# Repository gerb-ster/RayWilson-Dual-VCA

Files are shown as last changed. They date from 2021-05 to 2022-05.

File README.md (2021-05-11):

# Ray Wilson's Dual VCA

Somewhere I read that you can never have enough VCA’s, and I’ve build a number of them over the years. This one is a straight up clone of a design by the late Ray Wilson from Music From Outer Space. Really nice and versatile module.

## Status: Finished

- done: first schematic & board design
- done: breadboard and test
- done: design frontpanel
- done: order PCB and build prototype

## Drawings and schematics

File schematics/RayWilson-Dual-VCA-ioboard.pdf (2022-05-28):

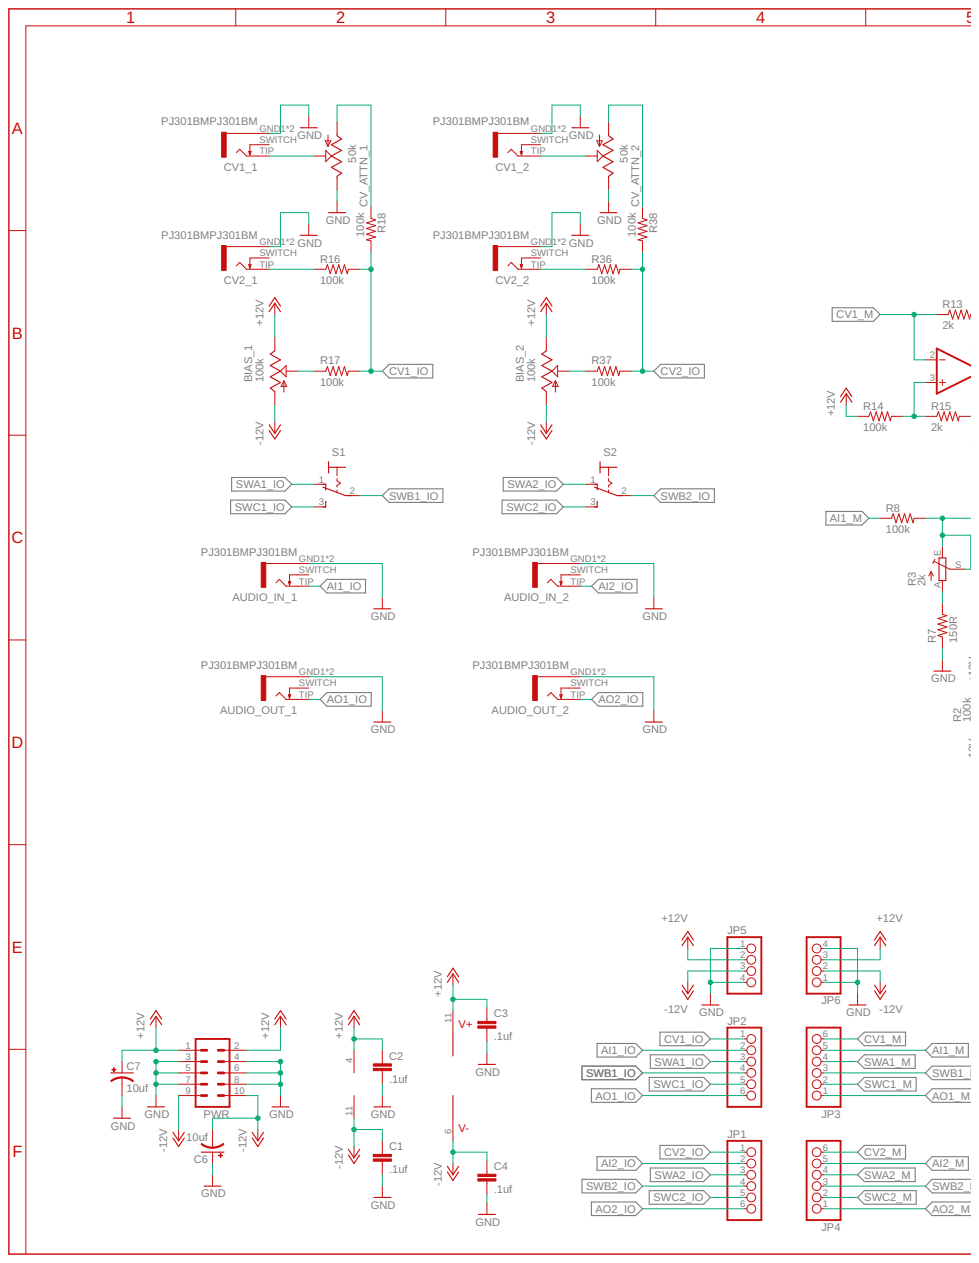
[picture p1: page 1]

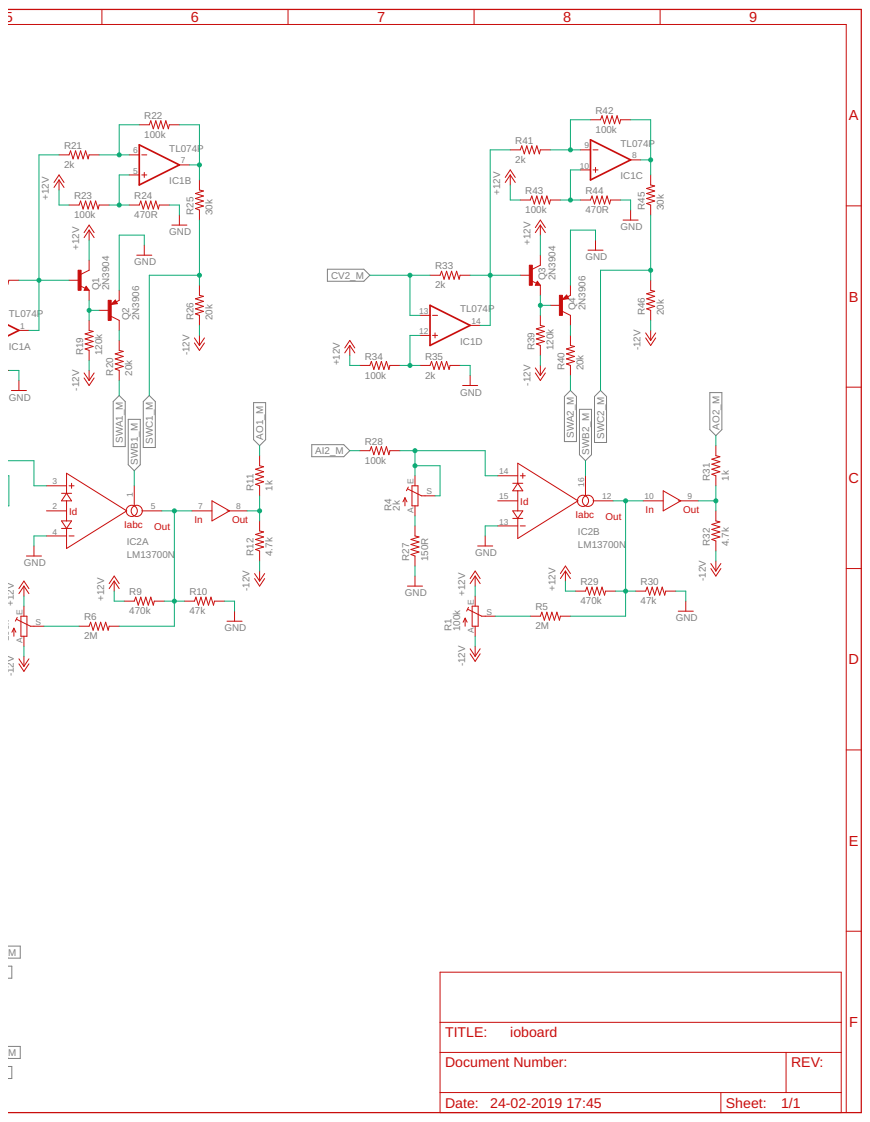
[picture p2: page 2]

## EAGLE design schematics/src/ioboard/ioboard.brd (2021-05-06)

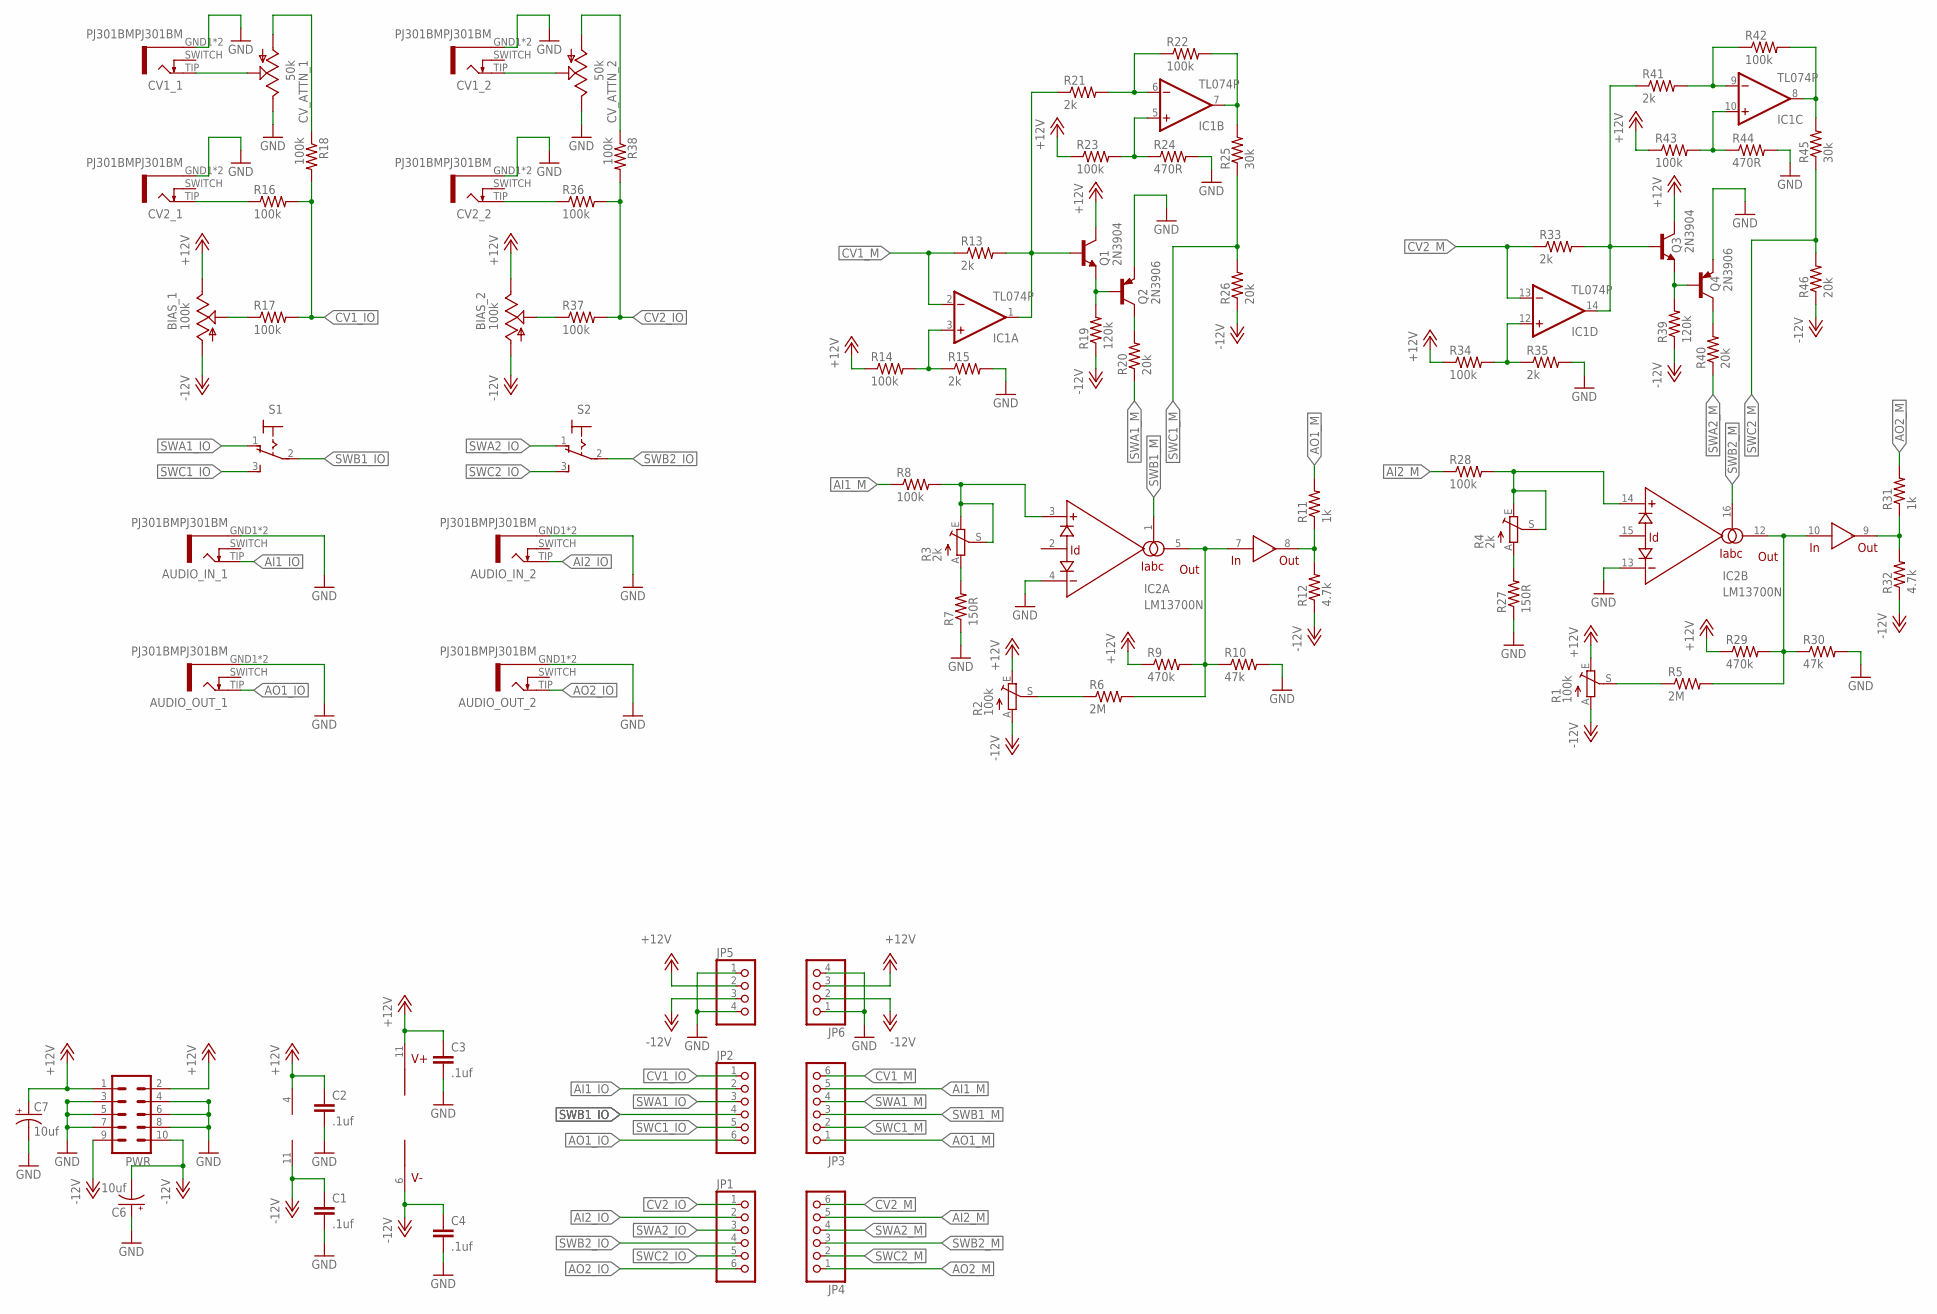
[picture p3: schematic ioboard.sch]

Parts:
AUDIO_IN_1, AUDIO_IN_2: PJ301BMPJ301BM; PJ301BM
AUDIO_OUT_1, AUDIO_OUT_2: PJ301BMPJ301BM; PJ301BM
BIAS_1, BIAS_2: 100k; EVUF
C1, C2, C3, C4: .1uf; C050-024X044
C6, C7: 10uf; E2,5-5
CV1_1, CV1_2, CV2_1, CV2_2: PJ301BMPJ301BM; PJ301BM
CV_ATTN_1, CV_ATTN_2: 50k; EVUF
IC1: TL074P; DIL14
IC2: LM13700N; DIL16
JP1, JP2, JP3, JP4: PINHD-1X6; 1X06
JP5, JP6: PINHD-1X4; 1X04
PWR: ML10
Q1, Q3: 2N3904; TO92
Q2, Q4: 2N3906; TO92
R1, R2: 100k; S64YW
R3, R4: 2k; S64YW
R5, R6: 2M; 0204/7
R7, R27: 150R; 0204/7
R8, R14, R16, R17, R18, R22, R23, R28, R34, R36, R37, R38, R42, R43: 100k; 0204/7
R9, R29: 470k; 0204/7
R10, R30: 47k; 0204/7
R11, R31: 1k; 0204/7
R12, R32: 4.7k; 0204/7
R13, R15, R21, R33, R35, R41: 2k; 0204/7
R19, R39: 120k; 0204/7
R20, R26, R40, R46: 20k; 0204/7
R24, R44: 470R; 0204/7
R25, R45: 30k; 0204/7
S1, S2: M9040P

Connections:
+12V: BIAS_1.3 (E), BIAS_2.3 (E), C2.1, C3.1, C7.+, IC1.4 (V+), IC2.11 (V+), JP5.2, JP6.3, PWR.1, PWR.2, Q1.1 (C), Q3.1 (C), R1.E, R2.E, R9.1, R14.1, R23.1, R29.1, R34.1, R43.1
-12V: BIAS_1.1 (A), BIAS_2.1 (A), C1.1, C4.1, C6.-, IC1.11 (V-), IC2.6 (V-), JP5.3, JP6.2, PWR.9, PWR.10, R1.A, R2.A, R12.1, R19.1, R26.1, R32.1, R39.1, R46.1
AI1_IO: AUDIO_IN_1.TIP (3), JP2.2
AI1_M: JP3.5, R8.1
AI2_IO: AUDIO_IN_2.TIP (3), JP1.2
AI2_M: JP4.5, R28.1
AO1_IO: AUDIO_OUT_1.TIP (3), JP2.6
AO1_M: JP3.1, R11.2
AO2_IO: AUDIO_OUT_2.TIP (3), JP1.6
AO2_M: JP4.1, R31.2
CV1_IO: JP2.1, R16.2, R17.2, R18.2
CV1_M: IC1.2 (-IN), JP3.6, R13.1
CV2_IO: JP1.1, R36.2, R37.2, R38.2
CV2_M: IC1.13 (-IN), JP4.6, R33.1
GND: AUDIO_IN_1.GND1 (5), AUDIO_IN_1.GND2 (5), AUDIO_IN_2.GND1 (5), AUDIO_IN_2.GND2 (5), AUDIO_OUT_1.GND1 (5), AUDIO_OUT_1.GND2 (5), AUDIO_OUT_2.GND1 (5), AUDIO_OUT_2.GND2 (5), C1.2, C2.2, C3.2, C4.2, C6.+, C7.-, CV1_1.GND1 (5), CV1_1.GND2 (5), CV1_2.GND1 (5), CV1_2.GND2 (5), CV2_1.GND1 (5), CV2_1.GND2 (5), CV2_2.GND1 (5), CV2_2.GND2 (5), CV_ATTN_1.3 (E), CV_ATTN_2.3 (E), IC2.4 (-IN), IC2.13 (-IN), JP5.1, JP5.4, JP6.1, JP6.4, PWR.3, PWR.4, PWR.5, PWR.6, PWR.7, PWR.8, Q2.3 (E), Q4.3 (E), R7.1, R10.2, R15.2, R24.2, R27.1, R30.2, R35.2, R44.2
IO_CV1: CV_ATTN_1.1 (A), R18.1
IO_CV2: CV_ATTN_2.1 (A), R38.1
unnamed: R2.S, R6.1
unnamed: R3.A, R7.2
unnamed: IC2.3 (+IN), R3.E, R3.S, R8.2
unnamed: IC2.5 (OUT), IC2.7 (IN), R6.2, R9.2, R10.1
unnamed: R4.A, R27.2
unnamed: IC2.8 (OUT), R11.1, R12.2
unnamed: BIAS_1.2 (S), R17.1
unnamed: IC1.1 (OUT), Q1.2 (B), R13.2, R21.1
unnamed: IC1.3 (+IN), R14.2, R15.1
unnamed: IC1.5 (+IN), R23.2, R24.1
unnamed: CV2_1.TIP (3), R16.1
unnamed: Q1.3 (E), Q2.2 (B), R19.2
unnamed: R1.S, R5.1
unnamed: Q2.1 (C), R20.2
unnamed: IC1.6 (-IN), R21.2, R22.1
unnamed: IC1.7 (OUT), R22.2, R25.2
unnamed: IC2.14 (+IN), R4.E, R4.S, R28.2
unnamed: IC2.10 (IN), IC2.12 (OUT), R5.2, R29.2, R30.1
unnamed: IC2.9 (OUT), R31.1, R32.2
unnamed: IC1.14 (OUT), Q3.2 (B), R33.2, R41.1
unnamed: IC1.12 (+IN), R34.2, R35.1
unnamed: Q3.3 (E), Q4.2 (B), R39.2
unnamed: Q4.1 (C), R40.2
unnamed: IC1.9 (-IN), R41.2, R42.1
unnamed: IC1.8 (OUT), R42.2, R45.2
unnamed: IC1.10 (+IN), R43.2, R44.1
unnamed: CV1_1.TIP (3), CV_ATTN_1.2 (S)
unnamed: CV1_2.TIP (3), CV_ATTN_2.2 (S)
unnamed: BIAS_2.2 (S), R37.1
unnamed: CV2_2.TIP (3), R36.1
SWA1_IO: JP2.3, S1.1 (O)
SWA1_M: JP3.4, R20.1
SWA2_IO: JP1.3, S2.1 (O)
SWA2_M: JP4.4, R40.1
SWB1_IO: JP2.4, S1.2
SWB1_M: IC2.1 (IABC), JP3.3
SWB2_IO: JP1.4, S2.2
SWB2_M: IC2.16 (IABC), JP4.3
SWC1_IO: JP2.5, S1.3 (S)
SWC1_M: JP3.2, R25.1, R26.2
SWC2_IO: JP1.5, S2.3 (S)
SWC2_M: JP4.2, R45.1, R46.2

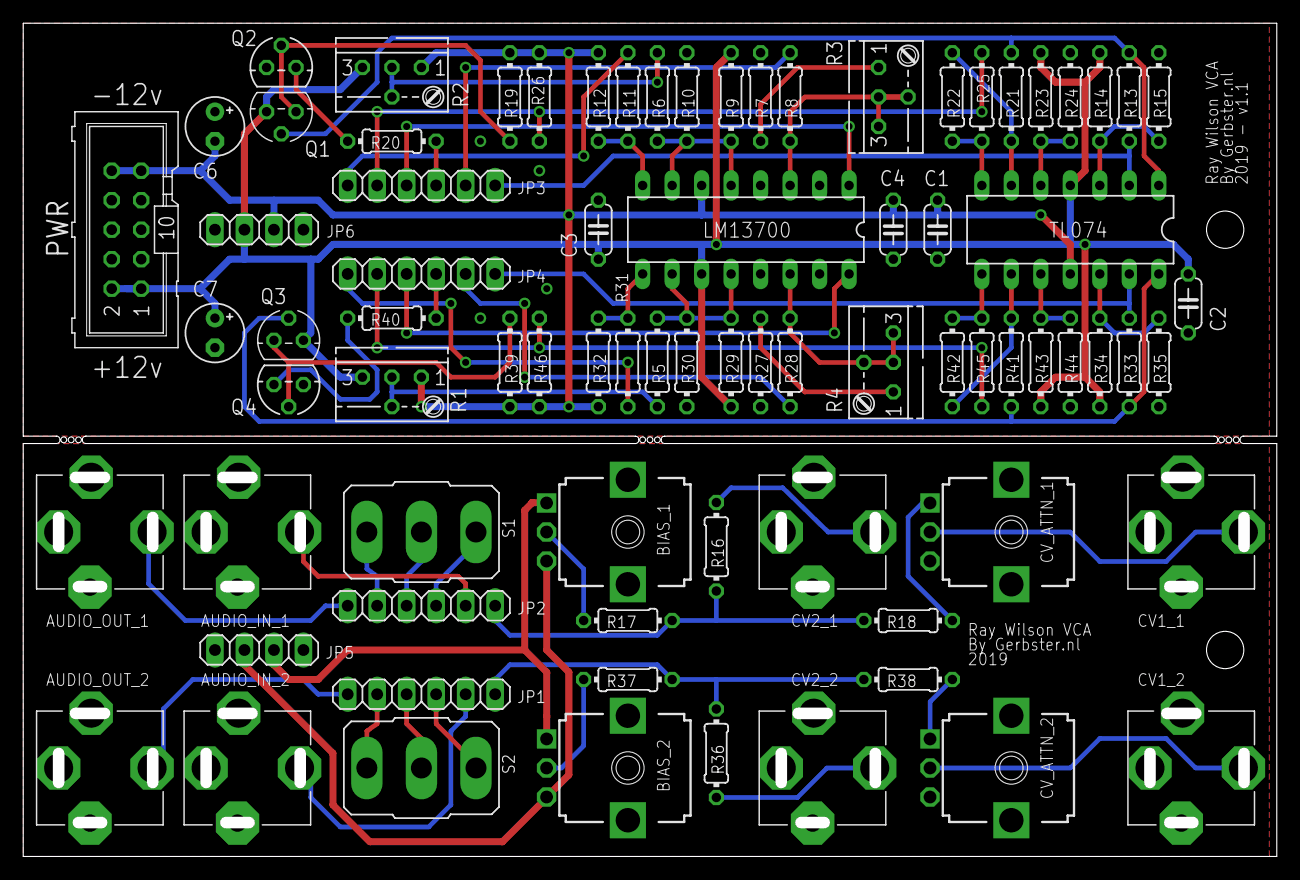
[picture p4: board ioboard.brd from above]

Board: 2 copper layers, 108.0 x 71.8 mm, 79 parts (0 on the bottom side), 59 nets.

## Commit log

2021-05-06 some files
    [RJW VCA.brd, RJW VCA.sch]
2021-05-07 Added files & structure
    [RayWilson-Dual-VCA-ioboard.GBL, RayWilson-Dual-VCA-ioboard.GBO, RayWilson-Dual-VCA-ioboard.GBP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]
2021-08-06 Updated some schematics and docs
    [RayWilson-Dual-VCA-ioboard.GBL, RayWilson-Dual-VCA-ioboard.GBO, RayWilson-Dual-VCA-ioboard.GBP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]
2021-08-10 Fixed some bugs and updated documentation
    [RayWilson-Dual-VCA-ioboard.XLN, gerber_job.gbrjob]
2022-04-20 Some updates & bugfixes
    [RayWilson-Dual-VCA-ioboard.XLN, gerber_job.gbrjob]
2022-04-22 Fixed schematics & descriptions
    [RayWilson-Dual-VCA-ioboard.XLN, gerber_job.gbrjob]
2022-05-17 Updated Firmware
    [RayWilson-Dual-VCA-ioboard.XLN, gerber_job.gbrjob]
2022-05-18 Updated Faceplates
    [RayWilson-Dual-VCA-ioboard.XLN, gerber_job.gbrjob]
2022-05-18 Fixed issues
    [RayWilson-Dual-VCA-ioboard.XLN, gerber_job.gbrjob]
2022-05-21 Fixed schematics
    [RayWilson-Dual-VCA-ioboard.XLN, gerber_job.gbrjob]
2022-05-28 General updates
    [RayWilson-Dual-VCA-ioboard.GKO, copper_bottom.gbr, copper_top.gbr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]
